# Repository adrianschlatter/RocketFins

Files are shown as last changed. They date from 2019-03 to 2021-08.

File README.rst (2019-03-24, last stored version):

PET-Bottle Waterrocket Fins
+++++++++++++++++++++++++++

This is a CAD-model of fins intended to be screwed onto a PET bottle to create a
water rocket. To create the rocket, you need:

- bottle with PCO-1881 threading (e.g. a 1.5-l Coke bottle)
- this part
- Gardena tap connector G 1"
- launcher

(+ water + pressurized air).

Use at your own risk.

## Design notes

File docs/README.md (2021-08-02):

# Fins for PET-Bottle Water-Rockets

<p align="middle">
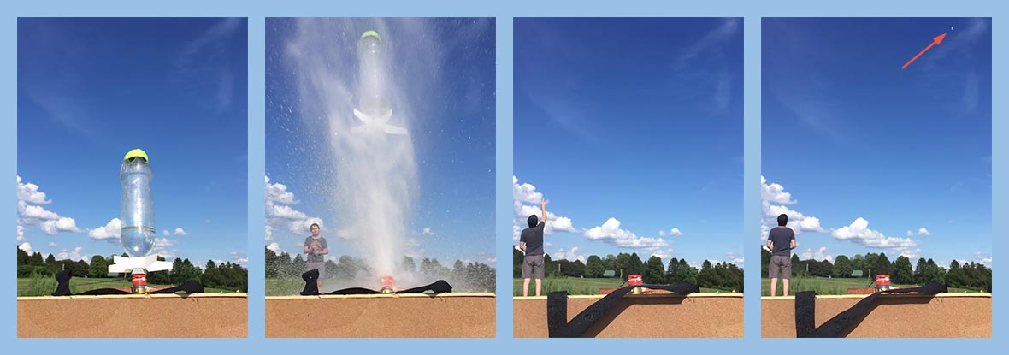
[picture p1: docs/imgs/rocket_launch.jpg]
Image strip showing finned Coke-bottle water-rocket launch

</p>

PET-bottle water rockets are fun. And if you have children, you already have
an engineering-, launch-, and recovery team. Let an adult take responsibility
for [safety](http://www.aircommandrockets.com/safety.htm): Exploding
pressure tanks (i.e., water rockets) are dangerous!
To learn more about water rockets, check out the excellent articles by 
[Air Command Water Rockets](http://www.aircommandrockets.com).
The usual way to create a very simple rocket is:

- glue fins to PET bottle
- glue nozzle to PET bottle
- tape nose cone to PET, possibly adding some weight for stable flight

Then bring your launch pad to some vast, empty area, fuel your rocket
with water, pressurize using a bicycle pump, and launch.

_Tricky part_: Glueing to PET.

_Solution_: Screw-on fins that also provide
a thread-adapter from PCO-1881 (PET-bottle thread) to 1" British
Standard Pipe Thread (Gardena(tm) tap-connector).

<p align="left">
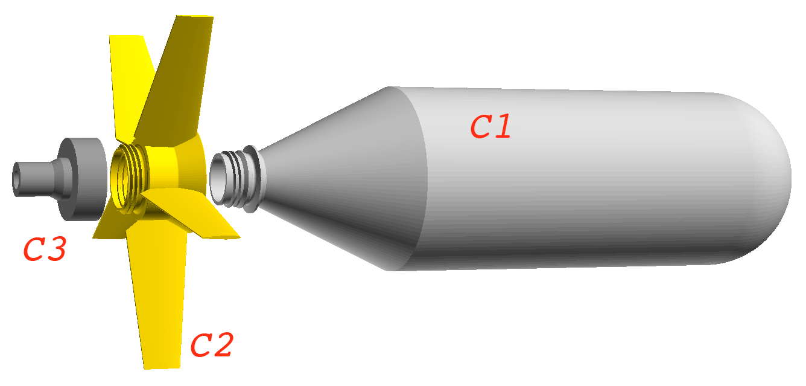
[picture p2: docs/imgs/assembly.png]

</p>

Note that the threads in C2 do _not_ act as seals: The lip of the bottle C1
will directly seal to the gasket inside the tap connector C3.

Some bottle-shapes may not fit into the fin-adapter. Coke bottles work nicely,
though. It should not matter much which type of garden hose connector you use
as long as it has a 1" British Standard Pipe Thread (often abbreviated
as G-1"). I use [these](https://www.gardena.com/int/products/watering/hose-fittings/tap-connector-33-3-mm-g-1/967312601/).

## Rocket-Fin Variants

These variants for C2 are currently available:

| Part-# | Name | Picture |
| ---| --- |--- |
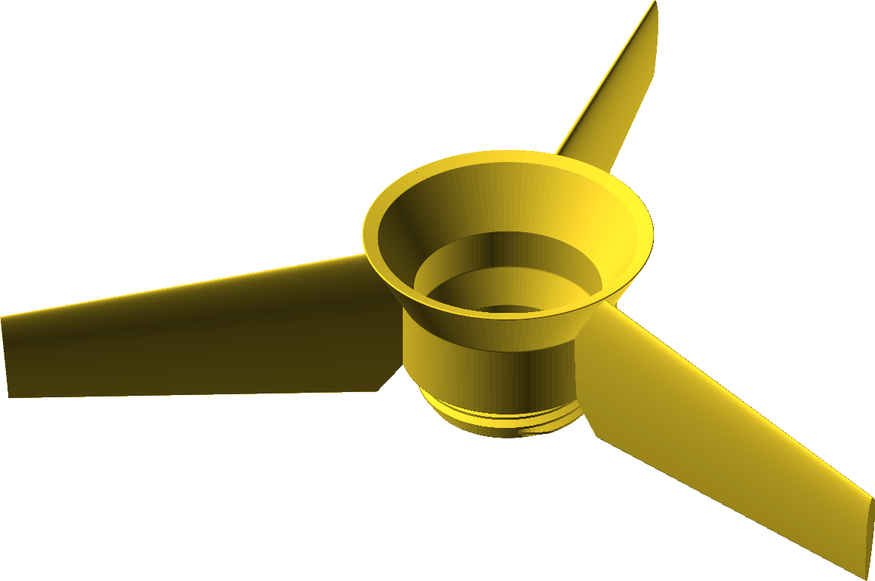
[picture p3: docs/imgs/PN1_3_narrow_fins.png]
| PN1  | 3 narrow fins  |  |
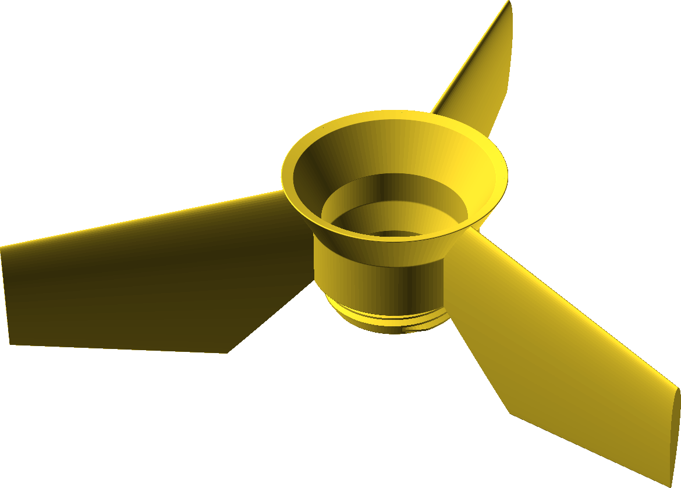
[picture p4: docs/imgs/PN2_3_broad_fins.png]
| PN2  | 3 broad fins |   |
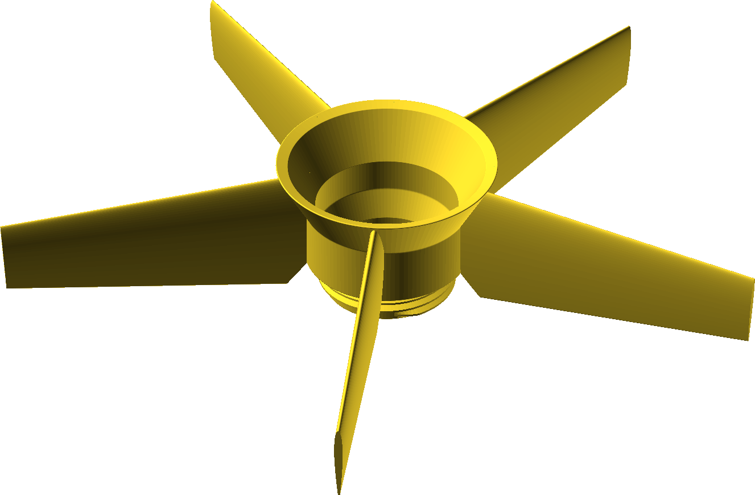
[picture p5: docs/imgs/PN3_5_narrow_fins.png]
| PN3  | 5 narrow fins  |  |

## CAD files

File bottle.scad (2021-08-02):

/*
A PET-Bottle

:author: Adrian Schlatter
*/

use <pco-1881.scad>


module bottle () {
    profile = [[0, 0],
               [26.19/2, 0],
               [46, 70],
               [46, 254],
               [0, 254]];

    translate([0, 0, 20])
        union() {
            rotate_extrude()
                polygon(points=profile);

            translate([0, 0, 254])
                sphere(r=46);

            translate([0, 0, -20])
                pco1881();
        };
};


bottle();

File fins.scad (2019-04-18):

// Points from n0009sm.dat in the archive: http://m-selig.ae.illinois.edu/ads/archives/coord_seligFmt.tar.gz
// Not necessarily in the same order as in: http://m-selig.ae.illinois.edu/ads/coord/n0009sm.dat

n0009sm_points = [[1000,0],[995.72,0.57],[982.96,2.18],[961.94,4.6299],[933.01,7.7],[896.68,11.27],[853.55,15.22],[804.38,19.4499],[750,23.84],[691.34,28.23],[629.41,32.47],[565.26,36.38],[500,39.78],[434.74,42.4799],[370.5899,44.31],[339.28,44.84],[308.66,45.09],[278.86,45.0399],[250,44.66],[222.21,43.97],[195.6199,42.95],[170.33,41.61],[146.45,39.94],[124.08,37.95],[103.32,35.64],[84.27,33.05],[66.9899,30.23],[51.56,27.2],[38.0599,23.95],[26.53,20.3899],[17.04,16.46],[9.61,12.14],[4.28,7.67],[1.07,3.49],[0,0],[1.07,-3.49],[4.28,-7.67],[9.61,-12.14],[17.04,-16.46],[26.53,-20.39],[38.0599,-23.95],[51.56,-27.2],[66.9899,-30.23],[84.27,-33.0501],[103.32,-35.64],[124.08,-37.95],[146.45,-39.9401],[170.33,-41.61],[195.6199,-42.95],[222.21,-43.97],[250,-44.66],[278.86,-45.04],[308.66,-45.09],[339.28,-44.84],[370.5899,-44.31],[434.74,-42.48],[500,-39.78],[565.26,-36.38],[629.41,-32.47],[691.34,-28.23],[750,-23.84],[804.38,-19.45],[853.55,-15.22],[896.68,-11.27],[933.01,-7.7],[961.94,-4.63],[982.96,-2.18],[995.72,-0.57]];

module fin(L=90, Hcenter=40, Htip=20, r=0, inset=0)
// Hcenter and Htip: Length of profiles *before* rounding of edges and inset
// r: external corners are rounded to this radius (avoids unprintable thin trailing edge)
// inset: useful for negative volumes. Create a fin insed by wall-thickness and subtract
//        it from a full fin to get a hollow fin
{
    // shift points so that thickest point is ~ at x=0:
    p = [for(i = [0:len(n0009sm_points)-1]) n0009sm_points[i] + [-300, 0]];
    
    s = (Htip - 2 * inset) / (Hcenter - 2 * inset);
    rotate([0, 90, 0])  // parallel to +x-axis
        scale(0.001)
            linear_extrude(height=L*1000, scale=s)
                offset(delta=-inset*1000)    // decrease by inset (=later wall thickness)
                    offset(r=r*1000) offset(delta=-r*1000)  // rounded ext corners
                        scale(Hcenter)
                            polygon(points=p);
}

module hollowFin(L=90, Hcenter=40, Htip=20, r=0.7, d=0.5)
// Creates a hollowed-out fin with wall-thickness d
{
    s = Htip / Hcenter;
    dL = L / 10;
    s0 = 1 + (1-s) * dL/L;
    s1 = s + (1-s) * d/L;

    difference() {
        fin(L=L, Hcenter=Hcenter, Htip=Htip, r=r, inset=0);
        translate([-dL, 0, 0])  // hollowing
            fin(L=L-d+dL, Hcenter=s0*Hcenter, Htip=s1*Hcenter, r=r, inset=d);
    }
}    

module fins(L=90, Hcenter=40, Htip=20, r=0, nfins=3)
// create a set of regularily rotated fins
{
    dphi = 360 / nfins;
    for (angle=[0:dphi:360]) {
        rotate([0, 0, angle])
            fin(L, Hcenter, Htip, r=r);
    }
}

module hollowFins(L=90, Hcenter=40, Htip=20, r=0.7, d=0.5, nfins=3)
// create a set of regularily rotated hollow fins
// take care: they overlap in the center. It is assumed that you will remove
//            the central region later on.
{
    dphi = 360 / nfins;
    for (angle=[0:dphi:360]) {
        rotate([0, 0, angle])
            hollowFin(L, Hcenter, Htip, r=r, d=d);
    }
}

// DEMO

intersection() {
    color("Green")
        translate([-500, 0, -500])
            cube([1000, 1000, 1000]);
        hollowFins(r=0.7, d=0.7);
};

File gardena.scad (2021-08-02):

/*
Gardena Tap Connectors
++++++++++++++++++++++

Units in this file: Millimeter.

*/

use <threadlib/threadlib.scad>

// Generic

module gasket (r0=8, r1=12.5, d=3, $fn=120) {
    /*
    Flat ring gasket
    ++++++++++++++++

    r0: Hole diameter
    r1: Outer diameter
    d: Thickness
    */
    
    color("DarkSlateGray")
        difference() {
            cylinder(h=d, r=r1);
            translate([0, 0, -d])
                cylinder(h=3*d, r=r0);
        }
};

module nozzle(type="G1", section=[[16.8, 0], [19.5, 0], [19.5, -14], [10, -14],
                                   [10, -18], [8, -22], [8, -38], [4.5, -38],
                                   [4.5, -21], [7, -17], [7, -12], [16.8, -12]], $fn=120)
{
    designator = str(type, "-int");
    P = thread_specs(designator)[0];
    turns = (section[0][1] - section[11][1] - P) / P;
    union() {
        translate([0, 0, -section[11][1]])
            rotate_extrude()
                polygon(points=section);
        translate([0, 0, P / 2])
            thread(designator, turns=turns);
    };
};

// Special Cases

module gasket_gardena_G3o4() {
    gasket();
};

module gasket_gardena_G1() {
    gasket(r0=20/2, r1=31.5/2, d=3);
};

module nozzle_gardena_G3o4 () {
    nozzle(type="G3/4", section=[[13.25, 0], [16.5, 0], [16.5, -14], [10, -14],
                                 [10, -18], [8, -21], [8, -37.7], [4.5, -37.7],
                                 [4.5, -20], [7, -17], [7, -12], [13.25, -12]]);
};

module nozzle_gardena_G1 () {
    nozzle();
};


// Demo
intersection() {
    translate([-50, 0, -50])
        color("Green")
            cube(100);
    union() {
        gasket_gardena_G3o4();
        nozzle_gardena_G3o4();
    };
};

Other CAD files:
pco-1881.scad
BSPthread.scad
PN1_3_narrow_fins.scad
PN2_3_broad_fins.scad
PN3_5_narrow_fins.scad
WaterRocketAdapter1.scad
rocket.scad
rocket_fins.scad

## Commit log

2019-03-24 PCO-1881 Bottle Neck +++++++++++++++++++++
    A PCO-1881 bottle neck: This is where our waterrocket adapter will have
    to fit to.
    [pco-1881.scad]
2019-03-24 Gardena Tap Connectors ++++++++++++++++++++++
    Tap connectors G 1" and G 3/4".
    This is what we will screw onto the water-bottle adapter and that will
    create a smooth water jet. It will also connect to our launcher.
    [gardena.scad]
2019-03-24 British Standard Pipe Thread ++++++++++++++++++++++++++++
    Added module to create british standard pipe thread. For now,
    only the parallel version, not the tapered one.
    [BSPthread.scad]
2019-03-26 BSP thread tables ++++++++++++++++++
    Obtained tabulated data on BSP threads.
    Developed a simplifed design with robust parameters
    (i.e., with as much margin as possible given the
    tolerances in the specs).
    [BSPthread.xlsx]
2019-03-28 fixed error in external Dpitch calculation
    [BSPthread.xlsx]
2019-04-03 Updated BSPP_external_thread() and BSPP_internal_thread() to design with optimum margins (as insensitive to production tolerances as possible).
    [BSPthread.scad]
2019-04-06 Simplified code by including the radius of rotation in the section profile. Rotation to extrude thread is now always =0.
    [BSPthread.scad]
2019-04-06 Prepare THREAD_TABLE ++++++++++++++++++++
    As OpenSCAD does not support function pointers, it is not an extensible
    approach to calculate the thread specs from pitch and Dpitch. Instead, I
    pre-calculate *all* of the specs in a table. The idea is to extend this
    table with further threads (such as metric threads, conic threads,
    bottle threads, etc.) later on.
    Step 1: Calculate THREAD_TABLE in Excel.
    [BSPthread.xlsx]
2019-04-06 Create thread by designator +++++++++++++++++++++++++++
    Created generalized thread-module that creates a thread by looking up
    the designator in THREAD_TABLE.
    [BSPthread.scad, THREAD_TABLE.scad]
2019-04-06 BSPthread renamed to threadlib +++++++++++++++++++++++++++++++
    As it is now extensible to many types of threads => renamed to
    threadlib.
    Separated test code from production code.
    [THREAD_TABLE.scad, test.scad, threadlib.scad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]
2019-04-07 Docs and License ++++++++++++++++
    - README.rst
    - LICENSE
    - License in code files
    - nut and bolt to threadlib.scad (from test.scad)
    - added feature to be able to use custom threads (table argument)
    [THREAD_TABLE.scad, test.scad, threadlib.scad]
2019-04-07 Separate threadlib into its own repo +++++++++++++++++++++++++++++++++++++
    threadlib is now a project of its own => removed it from this repo.
    [THREAD_TABLE.scad, test.scad, threadlib.scad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]
2019-04-08 simplified gardena code (rotate_extrude + threadlib)
    [gardena.scad]
2019-04-08 simplified code. Based on threadlib.
    [pco-1881.scad]
2019-04-08 Fins and WaterRocketAdapter Type 1
    [WaterRocketAdapter1.scad, fins.scad]
2019-04-18 Radius- and wall-thickness controls
    [fins.scad]
2019-04-18 Adjustment due to threadlib update Commenting
    [WaterRocketAdapter1.scad]
2019-04-18 5-fin adapter, fixed problems with collisions.
    [WaterRocketAdapter1.scad]
2019-04-18 3-fin adapter with fixed collisions.
    [WaterRocketAdapter1.scad]
2019-04-18 3 high fins
    [WaterRocketAdapter1.scad]
2021-08-02 Fixed 3-argument cube() to 1-argument cube()
    [WaterRocketAdapter1.scad, gardena.scad, pco-1881.scad]
2021-08-02 - 3 variants of fin adapters in separate files ... - ... based on generic rocket_fins.scad - rocket with bottle, fins, and nozzle in rocket.scad
    [PN1_3_narrow_fins.scad, PN2_3_broad_fins.scad, PN3_5_narrow_fins.scad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]
2021-08-02 created model of a PET bottle
    [bottle.scad]
2021-08-02 Exploded Model of Water Rocket
    [rocket.scad]
